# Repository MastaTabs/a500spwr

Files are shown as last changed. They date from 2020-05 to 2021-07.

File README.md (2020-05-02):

# Amiga500 single power

This is a DCDC converter Module to fit in Rev. 6a+ Amiga 500 mainboards.
It will be soldered onto the mainboard and one can then use a 12V barrel jack power supply with the Amiga 500.

It can deliver upto 6A @ 5V and 500mA @ -12V. The 12V line is passed through.

It also adds a power switch to the machine on the backside.

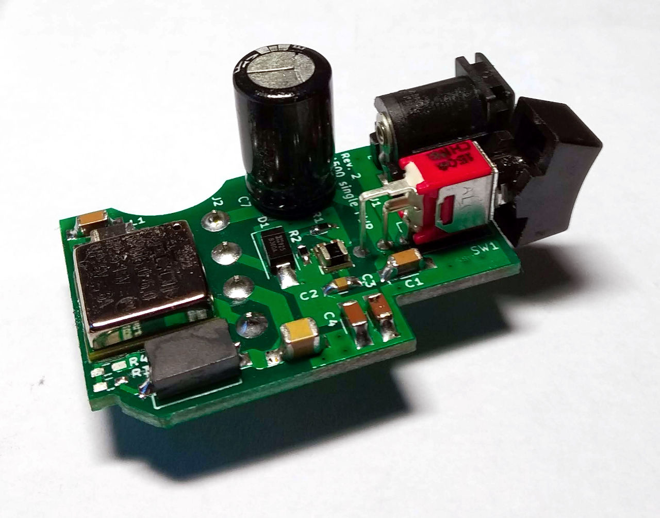
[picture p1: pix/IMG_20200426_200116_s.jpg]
Board Image


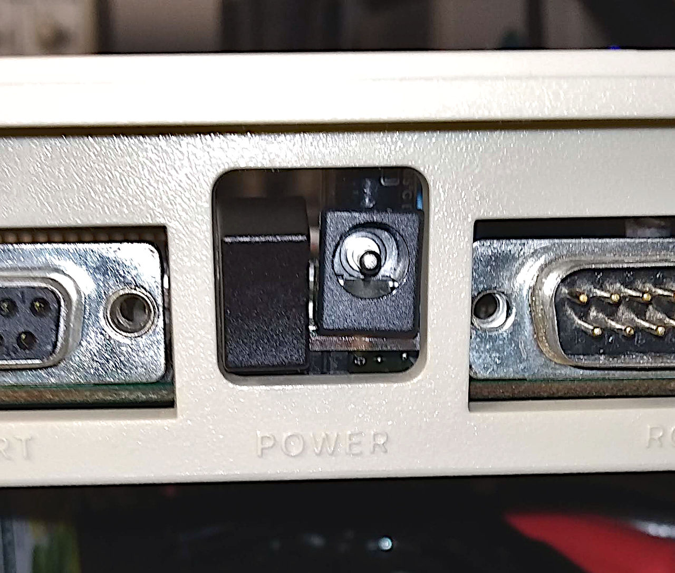
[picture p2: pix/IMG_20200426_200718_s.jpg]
A500 Backside


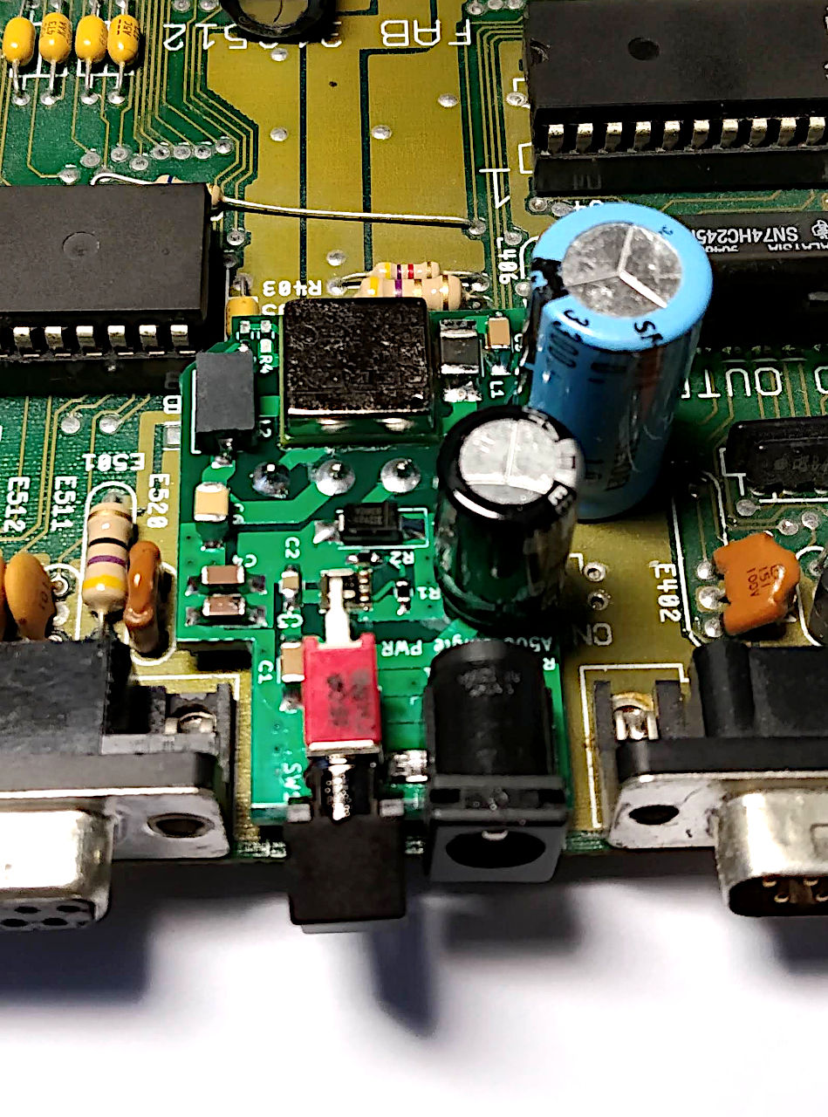
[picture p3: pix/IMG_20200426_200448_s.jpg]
A500 Inside


It has been tested by me and was found to be working good.

### License
The Amiga500 single power documentation, including the design itself, is copyright © MastaTabs (Tobias Seiler) 2020.

Amiga500 single power is Open Hardware licensed under the CERN OHL v. 1.2.

You may redistribute and modify this documentation under the terms of the CERN OHL v.1.2. This documentation is distributed as is and WITHOUT ANY EXPRESS OR IMPLIED WARRANTIES whatsoever with respect to its functionality, operability or use, including, without limitation, any implied warranties OF MERCHANTABILITY, SATISFACTORY QUALITY, FITNESS FOR A PARTICULAR PURPOSE or infringement. We expressly disclaim any liability whatsoever for any direct, indirect, consequential, incidental or special damages, including, without limitation, lost revenues, lost profits, losses resulting from business interruption or loss of data, regardless of the form of action or legal theory under which the liability may be asserted, even if advised of the possibility or likelihood of such damages.

A copy of the full license is included in file LICENSE.pdf, please refer to it for applicable conditions. In order to properly deal with its terms, please see file LICENSE_HOWTO.pdf.

The contact points for information about manufactured Products (see section 4.2) are listed in file PRODUCT.md.

Any modifications made by Licensees (see section 3.4.b) shall be recorded in file CHANGES.md.

The Documentation Location of the original project is https://github.com/MastaTabs/a500spwr.

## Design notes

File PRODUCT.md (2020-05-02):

## Manufacture and distribution of Products

Amiga500 single power is Open Hardware licensed under the CERN OHL v. 1.2.

Following is an excerpt from Section 4 of the [license](LICENSE.pdf) - **Manufacture and distribution of Products** - where *product* means *either an entire, or any part of a, device built using the Documentation or the modified Documentation*:

> 4.1. The Licensee may manufacture or distribute *Products* always provided that, where such manufacture or distribution requires a licence under this Licence the Licensee provides to each recipient of such Products an easy means of accessing a copy of the Documentation or modified Documentation, as applicable, as set out in section 3.

> 4.2. The Licensee is invited to inform any Licensor who has indicated his wish to receive this information about the type, quantity and dates of production of Products the Licensee has (had) manufactured

This file contains a list of the contact point wishing to receive information about manufactured Products.

### (Name) (E-Mail or other contact details)
- MastaTabs <mastatabs@gmail.com>

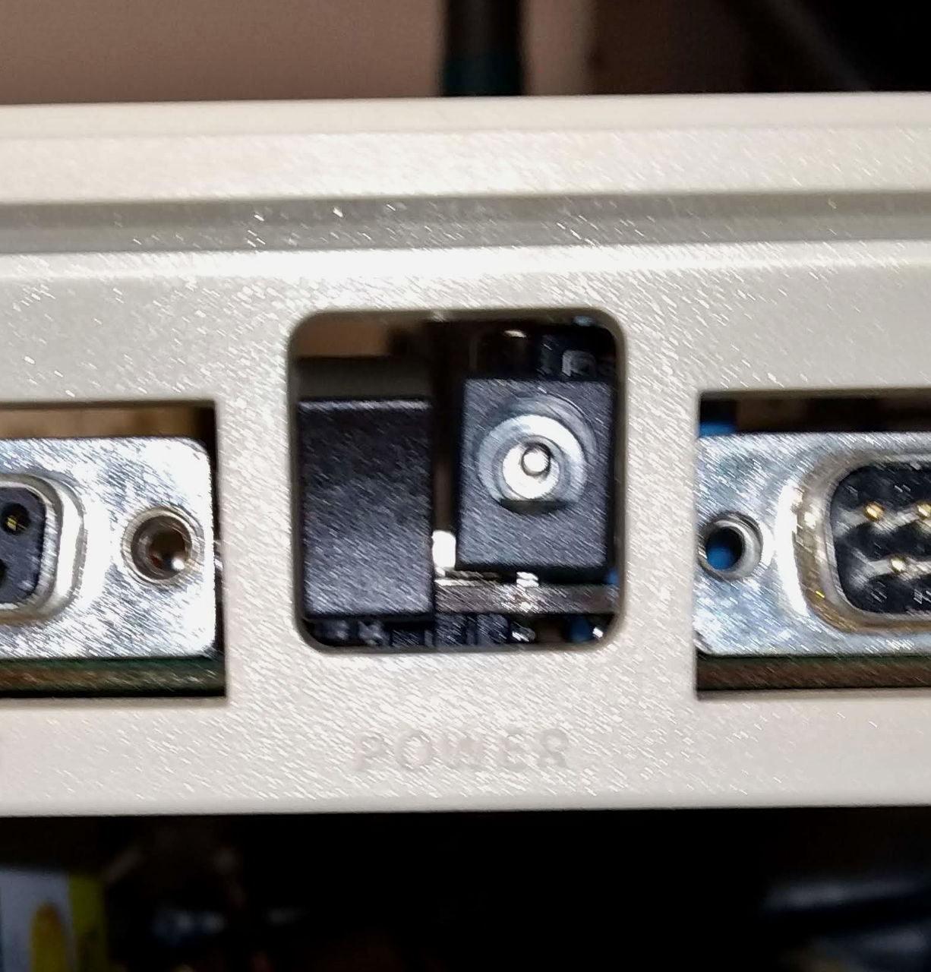
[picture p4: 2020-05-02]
pix/IMG_20200426_200743_s.jpg

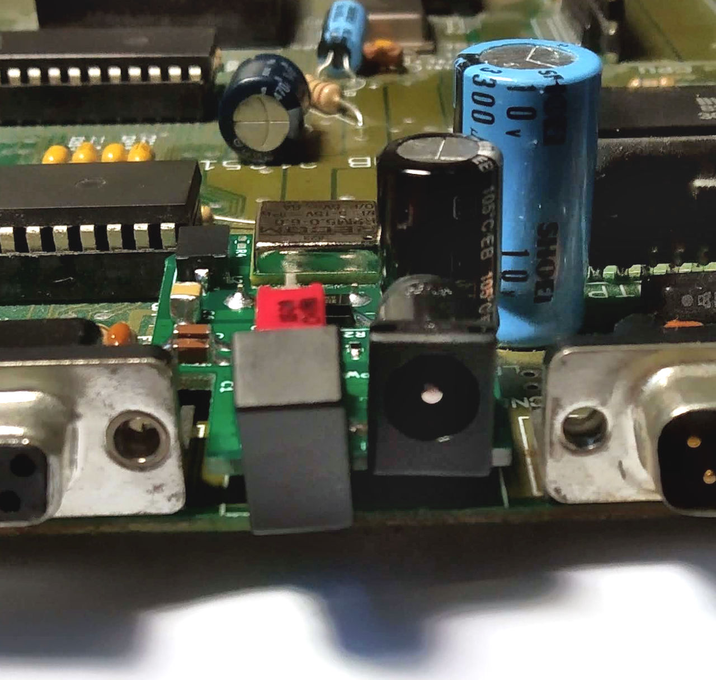
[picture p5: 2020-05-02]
pix/IMG_20200426_200426_s.jpg

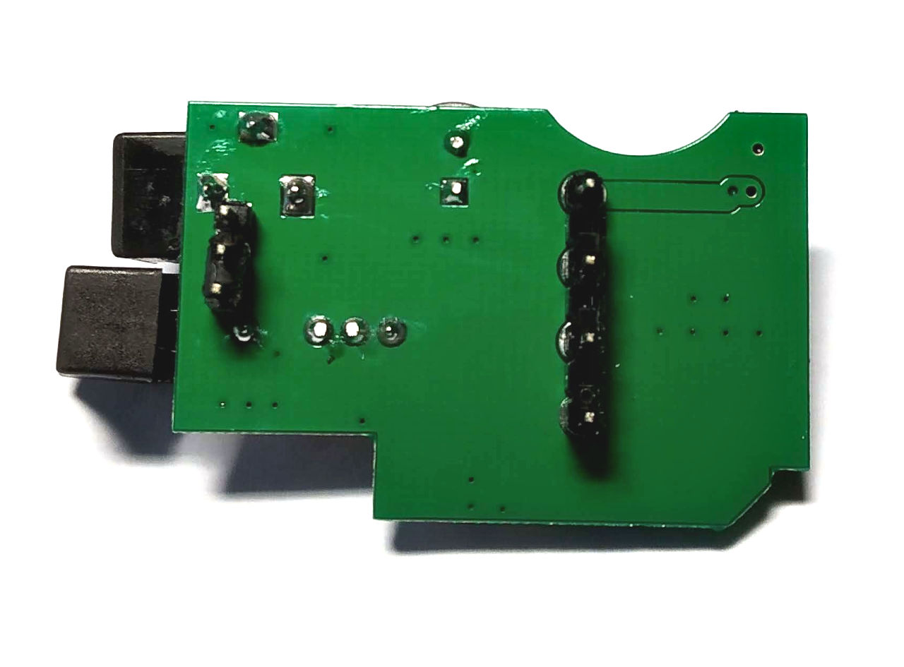
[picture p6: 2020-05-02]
pix/IMG_20200426_200208_s.jpg

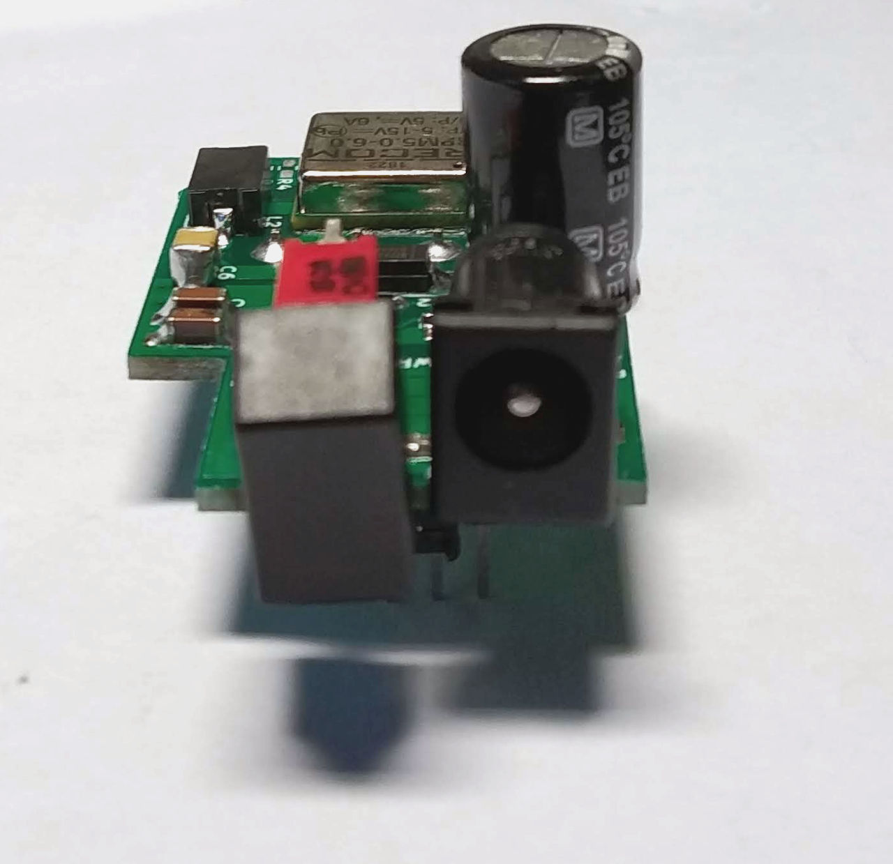
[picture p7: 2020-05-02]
pix/IMG_20200426_200145_s.jpg

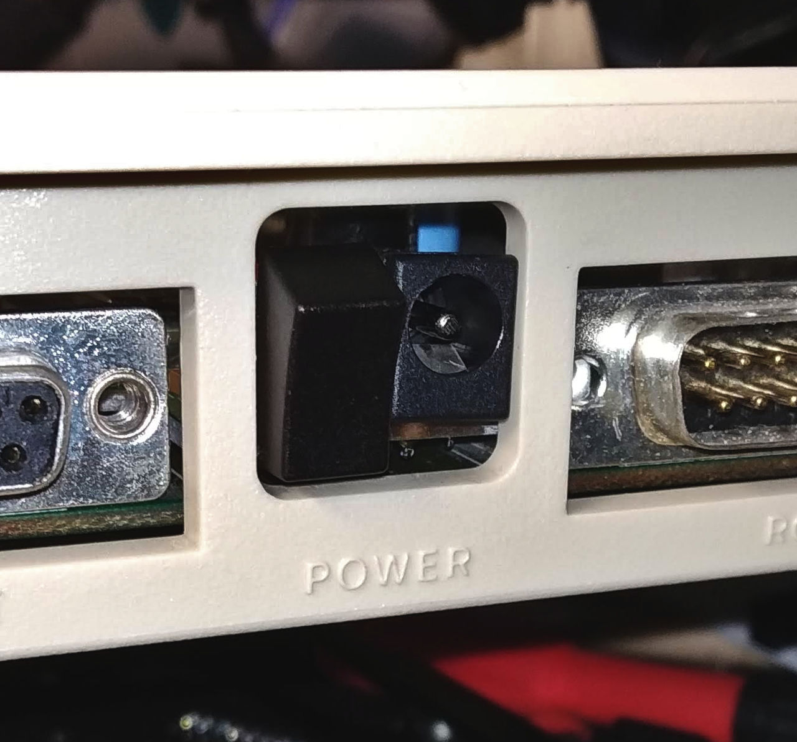
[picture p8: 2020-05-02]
pix/IMG_20200426_200724_s.jpg

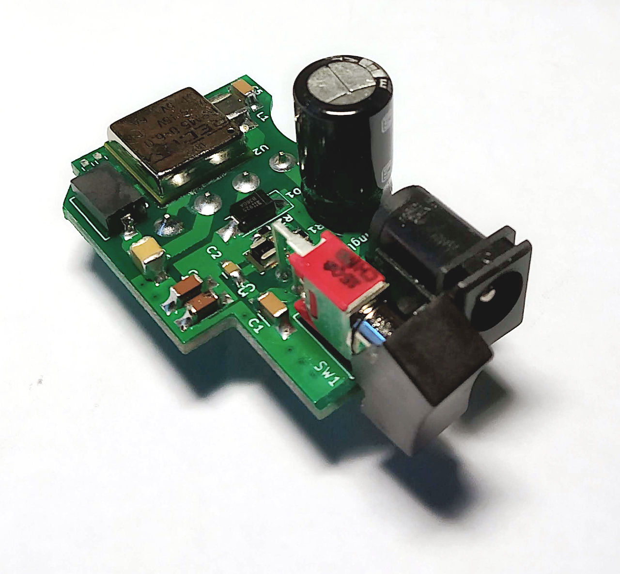
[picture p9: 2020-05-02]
pix/IMG_20200426_200133_s.jpg

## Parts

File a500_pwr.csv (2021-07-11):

Source: | /home/masta/Desktop/projects/a500_power/a500_pwr/a500_pwr.sch
Date: | Sa 02 Mai 2020 11:50:38 CEST
Tool: | Eeschema 5.1.5
Generator: | /usr/share/kicad/plugins/bom_csv_grouped_by_value.py
Component Count: | 20
Individual Components:
Item | Qty | Reference(s) | Value | LibPart | Footprint | Datasheet | Category | DK_Datasheet_Link | DK_Detail_Page | Description | Digi-Key_PN | Family | Herstellernr. | MPN | Manufacturer | Status
 |  | C1 | 10u 25V | Device:C_Small | Capacitors_SMD:C_1206_HandSoldering
 |  | C2 | 100n 50V | Device:C_Small | Capacitors_SMD:C_0805_HandSoldering |  |  |  |  |  |  |  | C2012X7R2A104K125AA
 |  | C3 | 10u | Device:C_Small | Capacitors_SMD:C_1206_HandSoldering |  |  |  |  |  |  |  | CGA5L1X7R1V106K160AC
 |  | C4 | 10u | Device:C_Small | Capacitors_SMD:C_1206_HandSoldering |  |  |  |  |  |  |  | CGA5L1X7R1V106K160AC
 |  | C5 | 10u 25V | Device:C_Small | Capacitors_SMD:C_1206_HandSoldering
 |  | C6 | 22u | Device:C_Small | Capacitors_SMD:C_1206_HandSoldering |  |  |  |  |  |  |  | C3216X5R1V226M160AC
 |  | C7 | 330u | Device:C | Capacitors_THT:CP_Radial_D8.0mm_P3.50mm
 |  | D1 | 700mV | Device:D_Schottky_Small | Diodes_SMD:D_SMA_Handsoldering |  |  |  | /product-detail/de/diodes-incorporated/B360A-13-F/B360A-FDICT-ND/724980 | DIODE SCHOTTKY 60V 3A SMA |  |  | B360A-13-F |  | Diodes Incorporated
 |  | J1 | PJ-102A | barreljack:PJ-102A | a500_pwr:Barrel_Jack_5.5mmODx2.1mmID_PJ-102A | https://www.cui.com/product/resource/digikeypdf/pj-102a.pdf | Connectors, Interconnects | https://www.cui.com/product/resource/digikeypdf/pj-102a.pdf | /product-detail/en/cui-inc/PJ-102A/CP-102A-ND/275425 | CONN PWR JACK 2X5.5MM SOLDER | CP-102A-ND | Barrel - Power Connectors |  | PJ-102A | CUI Inc. | Active
 |  | J2 | APWR_big | connect:Conn_01x04 | a500_pwr:APWR_big
 |  | J3 | APWR_small | connect:Conn_01x03 | a500_pwr:APWR_small |  | Connectors, Headers |  |  | 3 pin header 2.54mm
 |  | L1 | 742792510 | Device:Ferrite_Bead_Small | Capacitors_SMD:C_1812_HandSoldering | https://www.mouser.de/datasheet/2/445/742792510-1720733.pdf |  |  | product-detail/de/würth-elektronik/742792510/732-1640-1-ND/1639584 | FERRITE BEAD 70 OHM 1812 1LN | 732-1640-1-ND |  | 742792510 |  | Würth
 |  | L2 | 7427932 | Device:Ferrite_Bead_Small | a500_pwr:fb_5v | https://www.mouser.de/datasheet/2/445/7427932-1720978.pdf |  |  | /product-detail/de/würth-elektronik/7427932/732-2394-1-ND/2268596 | FERRITE BEAD 98 OHM 2SMD 1LN | 732-2394-1-ND |  | 7427932 |  | Würth
 |  | R1 | 280k 1% | Device:R_Small | Capacitors_SMD:C_0603_HandSoldering | https://www.mouser.de/datasheet/2/427/dcrcwe3-45987.pdf |  |  |  |  |  |  | CRCW0603280KFKEA
 |  | R2 | 25.5k | Device:R_Small | Capacitors_SMD:C_0603_HandSoldering | https://www.mouser.de/datasheet/2/427/dcrcwe3-45987.pdf |  |  |  |  |  |  | CRCW060325K5FKEA
 |  | R3 | Rdown | Device:R_Small | Capacitors_SMD:C_0603_HandSoldering |  |  |  |  | optional 5V adjust
 |  | R4 | Rup | Device:R_Small | Capacitors_SMD:C_0603_HandSoldering |  |  |  |  | optional 5V adjust
 |  | SW1 | RMS1R102M7QES | a500_pwr:PWR_SW | a500_pwr:rock_sw | https://www.mouser.de/datasheet/2/418/NG_CD_2267087_A_2267087_c.dwg-680380.pdf |  |  | /products/de?keywords=RMS1R102M7QES | SWITCH ROCKER SPDT 3A 120V | 450-2074-ND |  | RMS1R102M7QES
 |  | U1 | LMZM23600SILT | a500_pwr:LMZM23601SILR | a500_pwr:SIL0010A | http://www.ti.com/general/docs/suppproductinfo.tsp?distId=26 |  |  | /product-detail/de/texas-instruments/LMZM23600SILT/296-49457-1-ND/9371296 | DC DC CONVERTER 2.5-15V | 296-49457-1-ND |  | LMZM23600SILT |  | Texas Instruments
 |  | U2 | RPM5.0-6.0 | a500_pwr:RPM5.0-6.0 | a500_pwr:RPM5.0-6.0 | https://www.mouser.de/datasheet/2/468/RPM-6.0-1398219.pdf |  |  | /product-detail/de/recom-power/RPM5-0-6-0/945-3256-1-ND/9644705 | 6A DC/DC-CONVERTER 'INNOLINE' SM | 945-3256-1-ND
Collated Components:
Item | Qty | Reference(s) | Value | LibPart | Footprint | Datasheet | Category | DK_Datasheet_Link | DK_Detail_Page | Description | Digi-Key_PN | Family | Herstellernr. | MPN | Manufacturer | Status
1 | 2 | C1, C5 | 10u 25V | Device:C_Small | Capacitors_SMD:C_1206_HandSoldering
2 | 1 | C2 | 100n 50V | Device:C_Small | Capacitors_SMD:C_0805_HandSoldering |  |  |  |  |  |  |  | C2012X7R2A104K125AA
3 | 2 | C3, C4 | 10u | Device:C_Small | Capacitors_SMD:C_1206_HandSoldering |  |  |  |  |  |  |  | CGA5L1X7R1V106K160AC
4 | 1 | C6 | 22u | Device:C_Small | Capacitors_SMD:C_1206_HandSoldering |  |  |  |  |  |  |  | C3216X5R1V226M160AC
5 | 1 | C7 | 330u | Device:C | Capacitors_THT:CP_Radial_D8.0mm_P3.50mm
6 | 1 | D1 | 700mV | Device:D_Schottky_Small | Diodes_SMD:D_SMA_Handsoldering |  |  |  | /product-detail/de/diodes-incorporated/B360A-13-F/B360A-FDICT-ND/724980 | DIODE SCHOTTKY 60V 3A SMA |  |  | B360A-13-F |  | Diodes Incorporated
7 | 1 | J1 | PJ-102A | barreljack:PJ-102A | a500_pwr:Barrel_Jack_5.5mmODx2.1mmID_PJ-102A | https://www.cui.com/product/resource/digikeypdf/pj-102a.pdf | Connectors, Interconnects | https://www.cui.com/product/resource/digikeypdf/pj-102a.pdf | /product-detail/en/cui-inc/PJ-102A/CP-102A-ND/275425 | CONN PWR JACK 2X5.5MM SOLDER | CP-102A-ND | Barrel - Power Connectors |  | PJ-102A | CUI Inc. | Active
8 | 1 | J2 | APWR_big | connect:Conn_01x04 | a500_pwr:APWR_big
9 | 1 | J3 | APWR_small | connect:Conn_01x03 | a500_pwr:APWR_small |  | Connectors, Headers |  |  | 3 pin header 2.54mm
10 | 1 | L1 | 742792510 | Device:Ferrite_Bead_Small | Capacitors_SMD:C_1812_HandSoldering | https://www.mouser.de/datasheet/2/445/742792510-1720733.pdf |  |  | product-detail/de/würth-elektronik/742792510/732-1640-1-ND/1639584 | FERRITE BEAD 70 OHM 1812 1LN | 732-1640-1-ND |  | 742792510 |  | Würth
11 | 1 | L2 | 7427932 | Device:Ferrite_Bead_Small | a500_pwr:fb_5v | https://www.mouser.de/datasheet/2/445/7427932-1720978.pdf |  |  | /product-detail/de/würth-elektronik/7427932/732-2394-1-ND/2268596 | FERRITE BEAD 98 OHM 2SMD 1LN | 732-2394-1-ND |  | 7427932 |  | Würth
12 | 1 | R1 | 280k 1% | Device:R_Small | Capacitors_SMD:C_0603_HandSoldering | https://www.mouser.de/datasheet/2/427/dcrcwe3-45987.pdf |  |  |  |  |  |  | CRCW0603280KFKEA
13 | 1 | R2 | 25.5k | Device:R_Small | Capacitors_SMD:C_0603_HandSoldering | https://www.mouser.de/datasheet/2/427/dcrcwe3-45987.pdf |  |  |  |  |  |  | CRCW060325K5FKEA
14 | 1 | R3 | Rdown | Device:R_Small | Capacitors_SMD:C_0603_HandSoldering |  |  |  |  | optional 5V adjust
15 | 1 | R4 | Rup | Device:R_Small | Capacitors_SMD:C_0603_HandSoldering |  |  |  |  | optional 5V adjust
16 | 1 | SW1 | RMS1R102M7QES | a500_pwr:PWR_SW | a500_pwr:rock_sw | https://www.mouser.de/datasheet/2/418/NG_CD_2267087_A_2267087_c.dwg-680380.pdf |  |  | /products/de?keywords=RMS1R102M7QES | SWITCH ROCKER SPDT 3A 120V | 450-2074-ND |  | RMS1R102M7QES
17 | 1 | U1 | LMZM23600SILT | a500_pwr:LMZM23601SILR | a500_pwr:SIL0010A | http://www.ti.com/general/docs/suppproductinfo.tsp?distId=26 |  |  | /product-detail/de/texas-instruments/LMZM23600SILT/296-49457-1-ND/9371296 | DC DC CONVERTER 2.5-15V | 296-49457-1-ND |  | LMZM23600SILT |  | Texas Instruments
18 | 1 | U2 | RPM5.0-6.0 | a500_pwr:RPM5.0-6.0 | a500_pwr:RPM5.0-6.0 | https://www.mouser.de/datasheet/2/468/RPM-6.0-1398219.pdf |  |  | /product-detail/de/recom-power/RPM5-0-6-0/945-3256-1-ND/9644705 | 6A DC/DC-CONVERTER 'INNOLINE' SM | 945-3256-1-ND

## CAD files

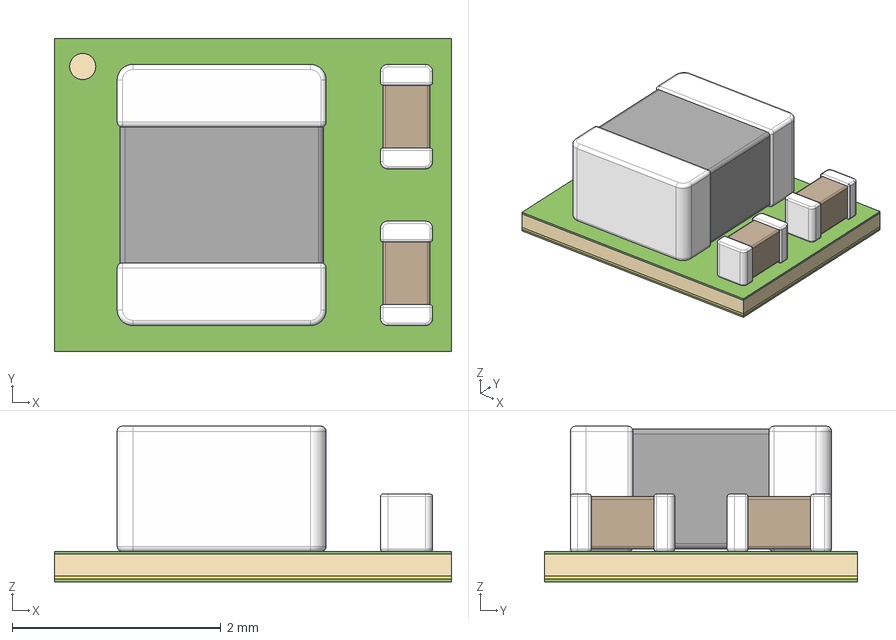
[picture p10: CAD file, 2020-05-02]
3d/SIL0010A.stp
3.80 x 3.00 x 1.49 mm
SOLDERMASK-BTM-SIL0010A
METAL-SIP
SUBSTRATE-SIP
SOLDERMASK-TOP
INDUCTOR-BODY
INDUCTOR-TERMNL x 2
CAP-BODY x 2
CAP-TERMNL x 4

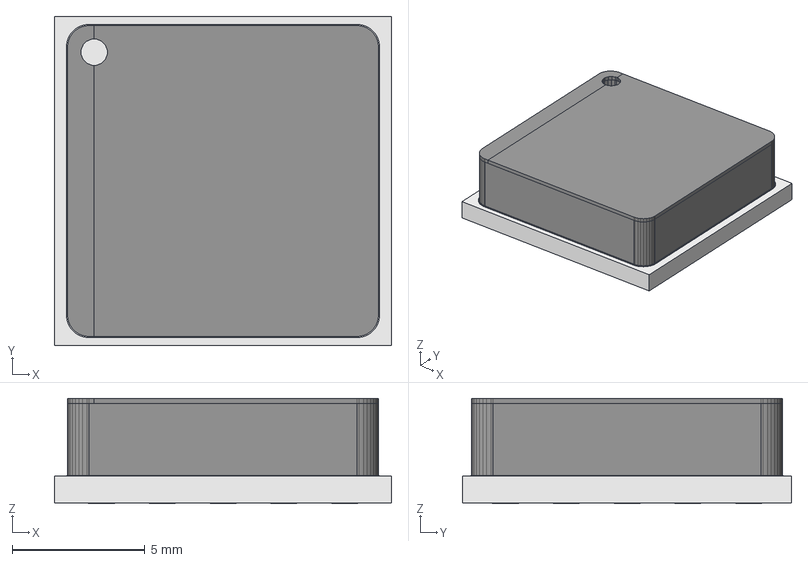
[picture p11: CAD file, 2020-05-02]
3d/RPM-6.0.step
12.7 x 12.4 x 3.97 mm
Extruded.step x 2
Extruded-0.step x 2
Extruded-1.step x 2
Extruded-2.step x 2
Extruded-3.step x 2
Extruded-4.step x 2
Extruded-5.step003 x 4
Extruded-6.step003 x 4
RPM_RBB_PCB028
RPM_RBB_PCB029
RPM_RBB_PCB030
RPM_RBB_PCB031
RPM_RBB_PCB032
RPM_RBB_PCB033
RPM_RBB_PCB034
RPM_RBB_PCB035
RPM_RBB_PCB036
RPM_RBB_PCB037
RPM_RBB_PCB038
RPM_RBB_PCB039
RPM_RBB_PCB040
RPM_RBB_PCB041
RPM_RBB_PCB042
RPM_RBB_PCB043
RPM_RBB_PCB044
RPM_RBB_PCB045
RPM_RBB_PCB046
RPM_RBB_PCB047
RPM_RBB_PCB048
RPM_RBB_PCB049
RPM_RBB_PCB050
RPM_RBB_PCB051
RPM_RBB_PCB052
RPM_RBB_PCB053
RPM_RBB_PCB054
RPM_RBB_PCB
RPM_RBB_PCB001
RPM_RBB_PCB002
RPM_RBB_PCB003
RPM_RBB_PCB004
RPM_RBB_PCB005
RPM_RBB_PCB006
RPM_RBB_PCB007
RPM_RBB_PCB008
RPM_RBB_PCB009
RPM_RBB_PCB010
RPM_RBB_PCB011
RPM_RBB_PCB012
RPM_RBB_PCB013
RPM_RBB_PCB014
RPM_RBB_PCB015
RPM_RBB_PCB016
RPM_RBB_PCB017
RPM_RBB_PCB018
RPM_RBB_PCB019
RPM_RBB_PCB020
RPM_RBB_PCB021
RPM_RBB_PCB022
RPM_RBB_PCB023
RPM_RBB_PCB024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

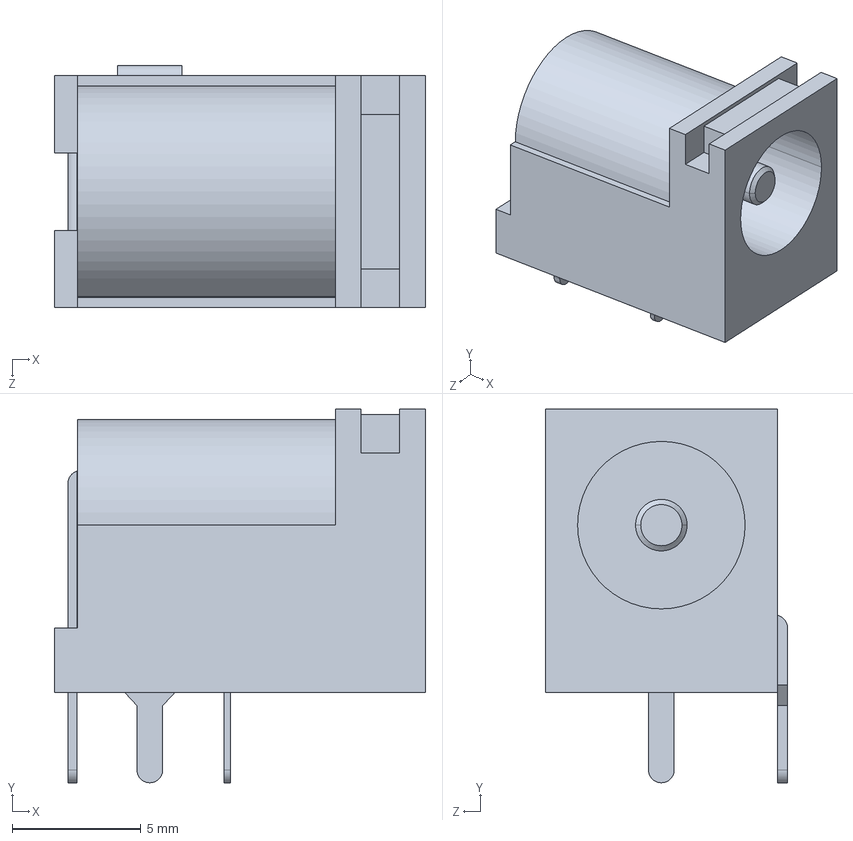
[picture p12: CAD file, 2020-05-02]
3d/CUI_DEVICES_PJ-102A.step
14.4 x 14.5 x 9.40 mm

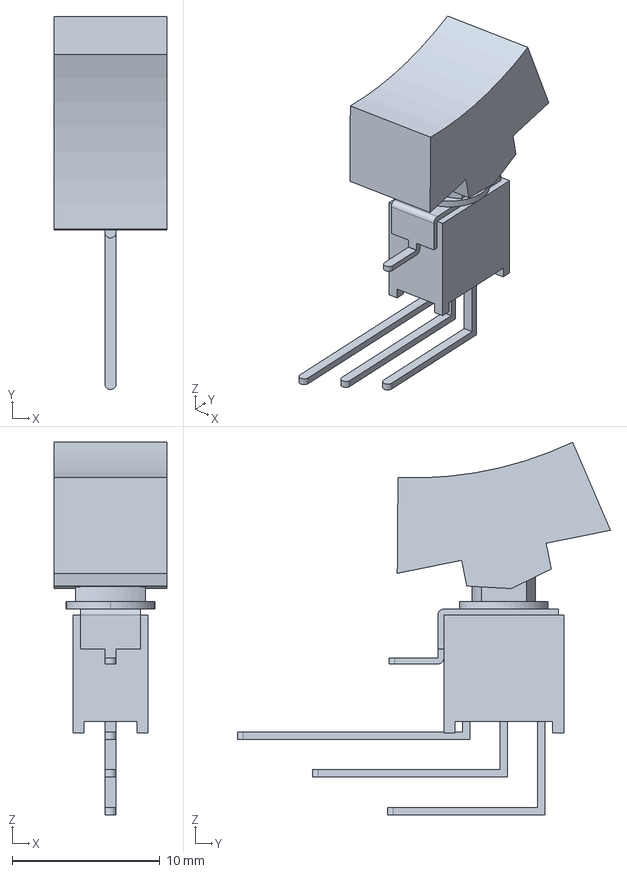
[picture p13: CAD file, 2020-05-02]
3d/c-2267087-5-a-3d.stp
7.62 x 25.3 x 25.2 mm

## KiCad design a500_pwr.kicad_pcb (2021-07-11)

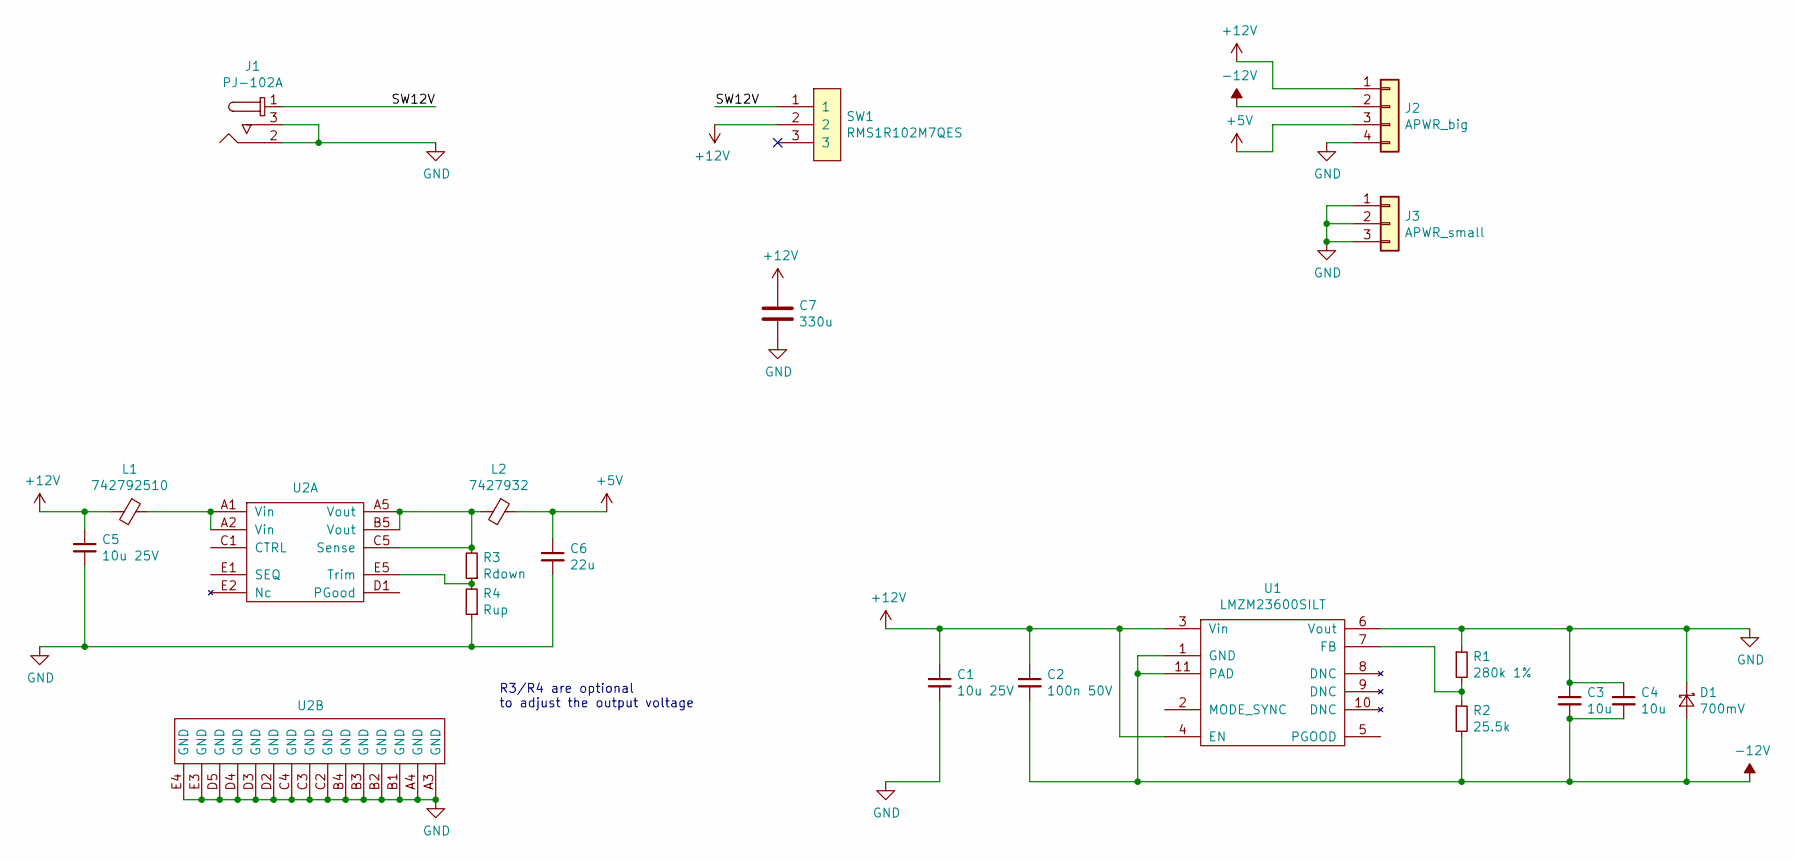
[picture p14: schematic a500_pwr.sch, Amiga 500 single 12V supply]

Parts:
C1, C5: 10u 25V; C_1206_HandSoldering
C2: 100n 50V; C_0805_HandSoldering
C3, C4: 10u; C_1206_HandSoldering
C6: 22u; C_1206_HandSoldering
C7: 330u; CP_Radial_D8.0mm_P3.50mm
D1: 700mV; D_SMA_Handsoldering
J1: PJ-102A; Barrel_Jack_5.5mmODx2.1mmID_PJ-102A; MPN PJ-102A; Digi-Key_PN CP-102A-ND
J2: APWR_big
J3: APWR_small
L1: 742792510; C_1812_HandSoldering; Digi-Key_PN 732-1640-1-ND
L2: 7427932; fb_5v; Digi-Key_PN 732-2394-1-ND
R1: 280k 1%; C_0603_HandSoldering
R2: 25.5k; C_0603_HandSoldering
R3: Rdown; C_0603_HandSoldering
R4: Rup; C_0603_HandSoldering
SW1: RMS1R102M7QES; rock_sw; Digi-Key_PN 450-2074-ND
U1: LMZM23600SILT; SIL0010A; Digi-Key_PN 296-49457-1-ND
U2: RPM5.0-6.0; Digi-Key_PN 945-3256-1-ND

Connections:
+5V: C6.1, J2.3, L2.1
+12V: C1.1, C2.1, C5.1, C7.1, J2.1, L1.2, SW1.2, U1.3 (Vin), U1.4 (EN)
-12V: C2.2, C3.2, C4.2, D1.2 (A), J2.2, R2.2, U1.1 (GND), U1.11 (PAD)
/SW12V: J1.1, SW1.1
GND: C1.2, C3.1, C4.1, C5.2, C6.2, C7.2, D1.1 (K), J1.2, J1.3, J2.4, J3.1, J3.2, J3.3, R1.1, R4.1, U1.6 (Vout), U2.A3 (GND), U2.A4 (GND), U2.B1 (GND), U2.B2 (GND), U2.B3 (GND), U2.B4 (GND), U2.C2 (GND), U2.C3 (GND), U2.C4 (GND), U2.D2 (GND), U2.D3 (GND), U2.D4 (GND), U2.D5 (GND), U2.E3 (GND), U2.E4 (GND)
unnamed: L1.1, U2.A1 (Vin), U2.A2 (Vin)
unnamed: L2.2, R3.2, U2.A5 (Vout), U2.B5 (Vout), U2.C5 (Sense)
unnamed: R1.2, R2.1, U1.7 (FB)
unnamed: R3.1, R4.2, U2.E5 (Trim)

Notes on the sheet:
R3/R4 are optional to adjust the output voltage

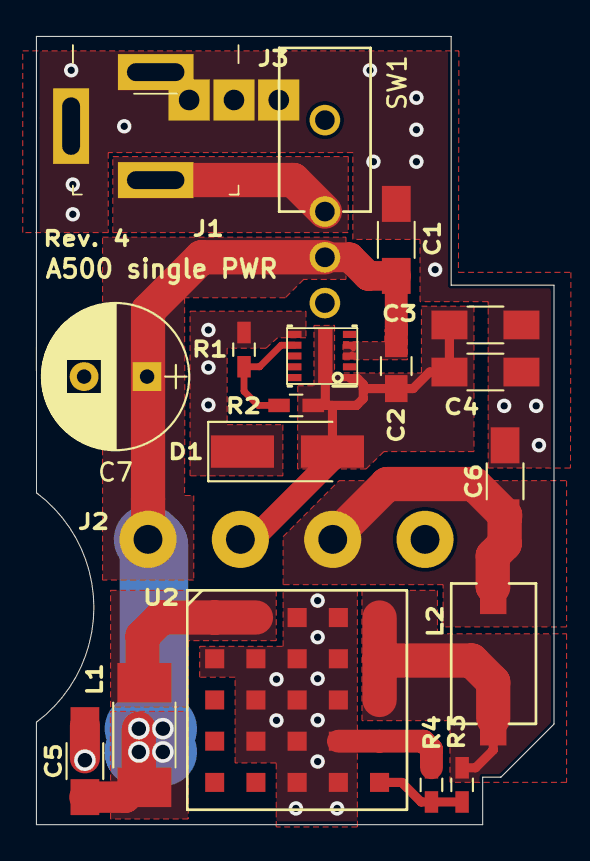
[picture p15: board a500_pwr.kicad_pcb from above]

Board: 2 copper layers, 28.8 x 43.8 mm, 20 parts (0 on the bottom side), 9 nets.

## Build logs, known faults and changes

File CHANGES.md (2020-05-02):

## CHANGES

Any modifications to the OpenAmigaJoyMouseSwitcher design and documentation made by any Licensee MUST be noted in this file, as per *section 3.4.b* of the [license](LICENSE.pdf).

### (Date) - (Author)
(Description)

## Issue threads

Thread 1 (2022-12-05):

LMZM23600 alternate part?

mfaircloth, 2022-12-05:
Given that the LMZM23600 is unobtanium at present, would you consider using a different part in the design?

MastaTabs, 2022-12-07:
The LMZM23601 is a direct dropin replacement but isn't available as well. I have tried to find a replacement part but haven't found anything easy to use that is small enough in size and available.
The LM2611 might be an option, but requires to design the circuit for the DCDC including two inductors yourself and might also only deliver 300mA @ -12V. But that needs to be tested first and that costs time and money again, especially if multiple revisions are needed.

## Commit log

2020-05-02 new BOM
    [a500_pwr.csv]
2020-05-16 adjust for different Barrel connector and note about R3/R4
    [a500_pwr.kicad_pcb, a500_pwr.sch]
2020-05-16 generated new gerbers (Rev. 3)
    [a500_pwr-B_Cu.gbl, a500_pwr-B_Mask.gbs, a500_pwr-B_Paste.gbp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]
2020-09-08 the PGOOD pin of the LMZM23600 was numbered 11 but 5 buy mistake, now the planes are correctly drawn without manual connect of the center pad
    [a500_pwr.kicad_pcb]
2020-09-08 for real now with new gerbers
    [a500_pwr-B_Cu.gbl, a500_pwr-B_Mask.gbs, a500_pwr-B_Paste.gbp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]
2020-09-15 again slipped
    [a500_pwr.sch]
2021-06-21 Fix C6 Mouser partnumber
    [a500_pwr.csv]
2021-06-21 Fix C6 Mouser part number
    [a500_pwr.sch]
2021-07-11 fix 22µF Mouser part number
    [a500_pwr.csv, a500_pwr.sch]
2021-07-11 thickend all 12V and 5V traces
    [a500_pwr.kicad_pcb]
2021-07-11 rev4 gerbers
    [a500_pwr-B_Cu.gbl, a500_pwr-B_Mask.gbs, a500_pwr-B_Paste.gbp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]
